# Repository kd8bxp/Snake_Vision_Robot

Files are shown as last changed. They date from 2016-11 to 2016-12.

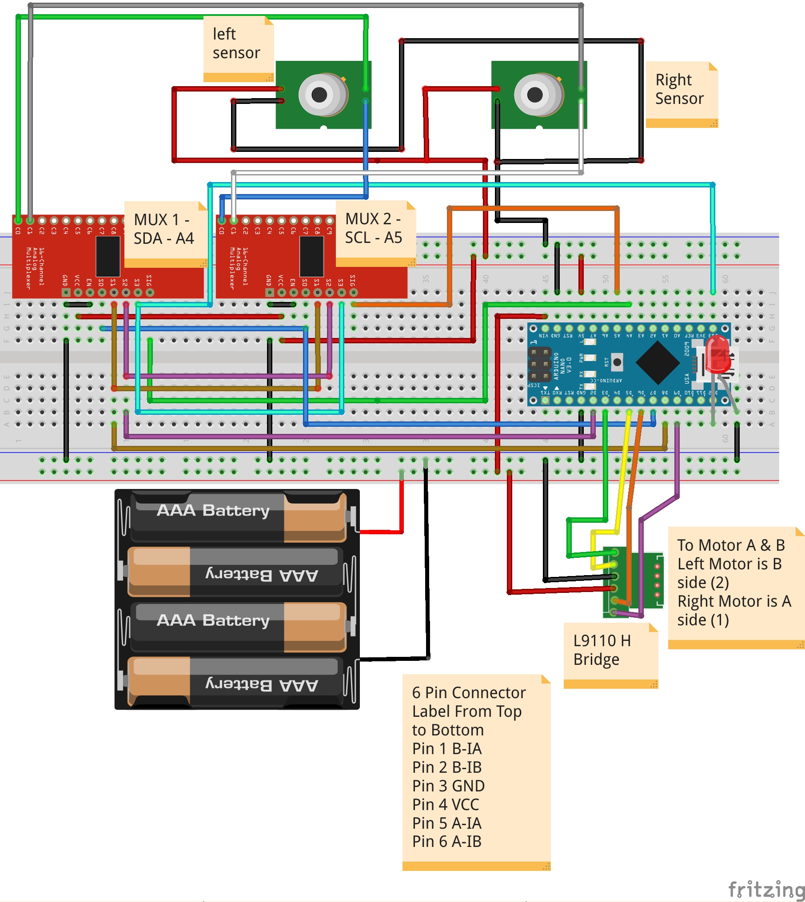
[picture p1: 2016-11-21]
documents/Snake Vision Robot_bb.jpg

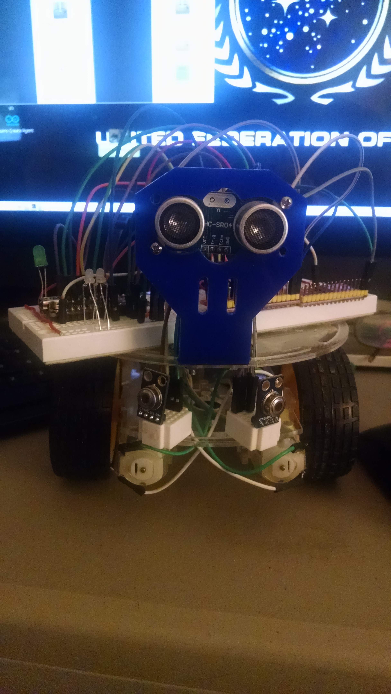
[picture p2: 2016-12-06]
documents/2016-12-05 19.06.58.jpg

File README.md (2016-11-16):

# Snake Vision Robot

The idea is that the robot is attracted to heat, and will move toward it.
The setup is to have the MLX90614 sensors set at an angle from each other, 
IF one sees more heat than the other, the robot will turn in that direction, and will attempt to move to the source.

The MLX90614 sensors were provided by IC Station for this experiment.
http://www.icstation.com/mlx90614esf-human-body-infrared-temperature-sensor-contact-temperature-module-p-9911.html

The sensors are I2C, and a MUX will be used to switch between the two sensors

## Parts

Heat Seeking robot based on 2 IC Station MLX90614ESF Human Body Infrared Temperature Sensors
Using a L9110 Motor Driver, and 2 CD74HC4067 MUX boards. 
With an Arduino Nano for it's brains.

## Contributing

1. Fork it!
2. Create your feature branch: `git checkout -b my-new-feature`
3. Commit your changes: `git commit -am 'Add some feature'`
4. Push to the branch: `git push origin my-new-feature`
5. Submit a pull request

## Credits

LeRoy Miller (2016).

## License

This program is free software: you can redistribute it and/or modify
    it under the terms of the GNU General Public License as published by
    the Free Software Foundation, either version 3 of the License, or
    (at your option) any later version.

    This program is distributed in the hope that it will be useful,
    but WITHOUT ANY WARRANTY; without even the implied warranty of
    MERCHANTABILITY or FITNESS FOR A PARTICULAR PURPOSE.  See the
    GNU General Public License for more details.

    You should have received a copy of the GNU General Public License
    along with this program.  If not, see <http://www.gnu.org/licenses>

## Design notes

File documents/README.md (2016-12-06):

# Snake Vision Robot

http://www.instructables.com/id/Snake-Vision-Robot-Using-Two-MLX90614-No-Contact-T/

## Not on Fritzing drawing

Updated parts list: on Dec 6, 2016 added a HC-SR04 ultrasonic sensor.
Echo Pin to Pin 10 on Nano
Trigger Pin to Pin 11 on Nano
VCC to 5v bus, GND to GND

## Contributing

1. Fork it!
2. Create your feature branch: `git checkout -b my-new-feature`
3. Commit your changes: `git commit -am 'Add some feature'`
4. Push to the branch: `git push origin my-new-feature`
5. Submit a pull request

## Credits

LeRoy Miller (2016).

## License

This program is free software: you can redistribute it and/or modify
    it under the terms of the GNU General Public License as published by
    the Free Software Foundation, either version 3 of the License, or
    (at your option) any later version.

    This program is distributed in the hope that it will be useful,
    but WITHOUT ANY WARRANTY; without even the implied warranty of
    MERCHANTABILITY or FITNESS FOR A PARTICULAR PURPOSE.  See the
    GNU General Public License for more details.

    You should have received a copy of the GNU General Public License
    along with this program.  If not, see <http://www.gnu.org/licenses>

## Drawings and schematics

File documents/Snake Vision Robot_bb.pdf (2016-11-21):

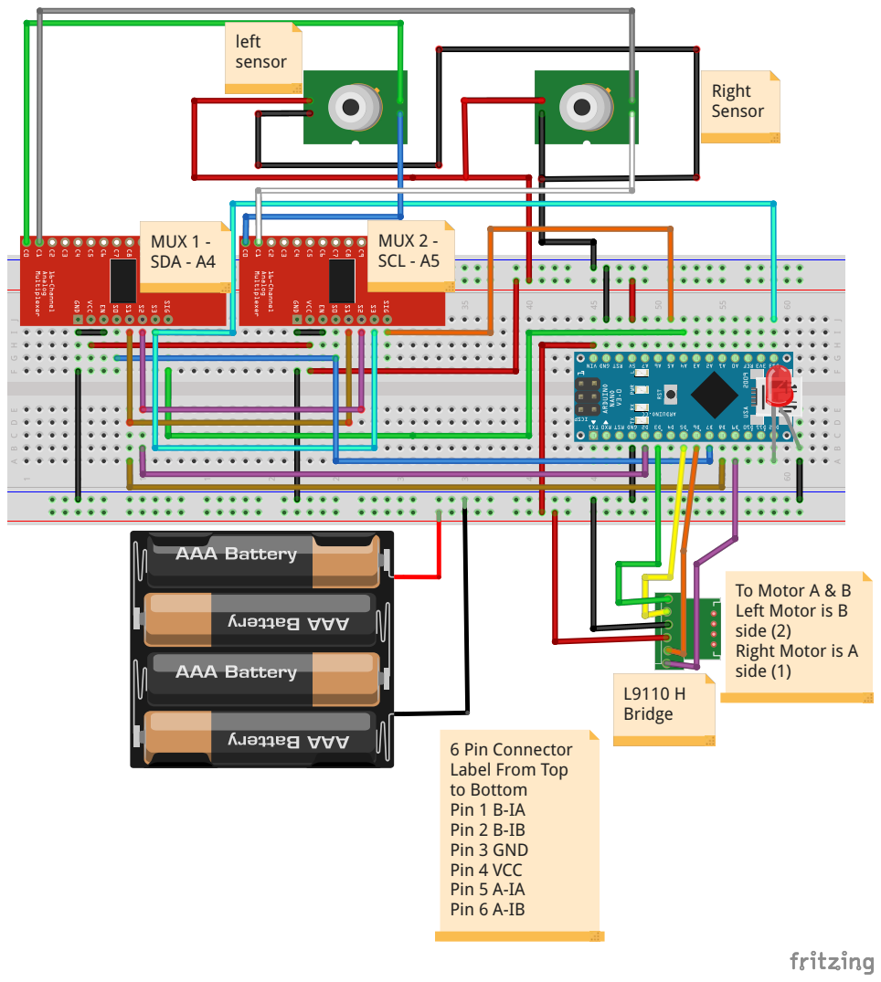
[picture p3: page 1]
L9110 H Bridge; MUX 1 - SDA - A4; MUX 2 - SCL - A5; left sensor; Right Sensor

To Motor A & B
Left Motor is B
side (2)
Right Motor is A
side (1)

6 Pin Connector
Label From Top
to Bottom
Pin 1 B-IA
Pin 2 B-IB
Pin 3 GND
Pin 4 VCC
Pin 5 A-IA
Pin 6 A-IB

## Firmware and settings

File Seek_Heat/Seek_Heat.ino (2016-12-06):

/* 2-Way motor control for the L9110 motor driver adapted from
 * https://www.bananarobotics.com/shop/How-to-use-the-HG7881-(L9110)-Dual-Channel-Motor-Driver-Module
 * 
 * Multiplexer code based on information found
 * http://bildr.org/2011/02/cd74hc4067-arduino/
 * and https://www.sparkfun.com/products/9056
 * 
 * Adapted by LeRoy Miller, 2016 (Copyright)
 * 
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
    You should have received a copy of the GNU General Public License
    along with this program.  If not, see <http://www.gnu.org/licenses>
 */

// Seek Heat.

#include <Wire.h>
#include <Adafruit_MLX90614.h>
#include <NewPing.h>

Adafruit_MLX90614 mlx = Adafruit_MLX90614(); 
#define units 1 //1=Fahrenheit,  0=Celius

//Functions:

//rightForward(speed)
//rightBackward(speed)
//leftForward(speed)
//leftBackward(speed)
//stop()
//readRightSensor() - set the mux to read the sensor connected to C0
//readLeftSensor() - set the mux to read the sensor connected to C1
//readSensor() - returns value of current readings

//Setup  variables for UltraSonic
int pingSensorIn;
int goRobotGo = 0; //Should the robot be moving or stopped
#define distance 5 //Stop distance in Inches
#define TRIGGER_PIN  11  // Arduino pin tied to trigger pin on the ultrasonic sensor.
#define ECHO_PIN     10  // Arduino pin tied to echo pin on the ultrasonic sensor.
#define MAX_DISTANCE 200 // Maximum distance we want to ping for (in centimeters). Maximum sensor distance is rated at 400-500cm.

NewPing sonar(TRIGGER_PIN, ECHO_PIN, MAX_DISTANCE); // NewPing setup of pins and maximum distance.


//Setup variables for motors
#define leftMotorPin1   3 //Left IA2   PWM PIN
#define leftMotorPin2   5 //Left IB2 Direction PIN 
#define rightMotorPin1  6 //Right IA1 PWM PIN
#define rightMotorPin2  9 //Right IB1 Direction PIN
#define pwmR  140 //smallest PWM value that will cause motor to spin
#define pwmL  125

//Setup variables for temperature sensors

int rightSensor;
int leftSensor;
int rightAmbient; //ambient temperature of sensors
int leftAmbient;
int rightCalibrate;
int leftCalibrate;
int aL;
int sL;
int aR;
int sR;


//Variables for Mux. (multiplexer)
/* Special cases - 2 Mux boards are used, one is used for SDA, and
 *  the other is used for SCL. There are two thermal sensors, so only
 *  2 of the 16 ports on the mux are needed, meaning, only one
 *  of the mux control lines needs to be changed to read the two sensors
 *  The code would need to be changed, and expanded to add more I2C sensors
 */

#define s0  7
#define s1  8
#define s2  2
#define s3 13

//RED temperatures are higher than ambient, GREEN ambient temperature
#define LED 12  //ready indicator (GREEN)
#define RIGHTREDLED A0 
#define RIGHTGREENLED A1
#define LEFTREDLED A2
#define LEFTGREENLED A3


void setup()   {  
   Serial.begin(9600);
   mlx.begin();
   pinMode(LED, OUTPUT);
   pinMode(s0, OUTPUT);
   pinMode(s1, OUTPUT);
   pinMode(s2, OUTPUT);
   pinMode(s3, OUTPUT);
   pinMode(RIGHTREDLED, OUTPUT);
   pinMode(RIGHTGREENLED, OUTPUT);
   pinMode(LEFTREDLED, OUTPUT);
   pinMode(LEFTGREENLED, OUTPUT);
   pinMode(leftMotorPin1, OUTPUT); 
   pinMode(leftMotorPin2, OUTPUT);  
   pinMode(rightMotorPin1, OUTPUT);
   pinMode(rightMotorPin2, OUTPUT);
   digitalWrite(s0, LOW);
   digitalWrite(s1, LOW);
   digitalWrite(s2, LOW);
   digitalWrite(s3, LOW);
   digitalWrite(RIGHTREDLED, LOW);
   digitalWrite(RIGHTGREENLED, LOW);
   digitalWrite(LEFTREDLED, LOW);
   digitalWrite(LEFTGREENLED, LOW);
  stop();
  delay(5000); //delay before calibration - warning sensors are very senitive point them away from any type of heat source.
  calibrateSensors(); 
 delay(5000);  //another delay after calibration (a buzzer might go good here, warning that the bot is just about ready)
 digitalWrite(LED, HIGH); //When LED comes on ROBOT is Ready to move.
 
}

void loop()                     
{

readRightSensor();
readLeftSensor();
readPing();
if (goRobotGo) {
aL = map(leftAmbient, -40, leftAmbient, 0.0, pwmR);
sL = map(leftSensor, leftAmbient, leftSensor, pwmR, 0.0);
aR = map(rightAmbient, -40, rightAmbient, 0.0, pwmL);
sR = map(rightSensor, rightAmbient, rightSensor, pwmL, 0.0);
if (leftAmbient >= leftSensor) {sL = pwmR;}
if (rightAmbient >= rightSensor) {sR = pwmL;}
rightForward(aL - sL);
leftForward(aR - sR);
} else { stop(); }
//delay(50); //test code with small delay (may not be needed)

}

void readPing() {
 
   unsigned int uS = sonar.ping(); // Send ping, get ping time in microseconds (uS).
   pingSensorIn = (uS / US_ROUNDTRIP_IN);
   if (pingSensorIn >= distance) {goRobotGo = 1; } else {goRobotGo = 0;}

}

void readRightSensor() {
  digitalWrite(s0, LOW);
  //because S1, S2, S3 are already set LOW we don't need to set again
  rightSensor = readSensor() + rightCalibrate;
  rightAmbient = readAmbient();
  if (rightAmbient >= rightSensor) { 
    digitalWrite(RIGHTGREENLED, HIGH); 
    digitalWrite(RIGHTREDLED, LOW); } else {
        digitalWrite(RIGHTGREENLED, LOW);
        digitalWrite(RIGHTREDLED, HIGH);
    }
  }

void readLeftSensor() {
  digitalWrite(s0, HIGH);
  //because s1, s2, s3 are already set LOW we don't need to set again
  leftSensor = readSensor() + leftCalibrate;
  leftAmbient = readAmbient();
  if (leftAmbient >= leftSensor) { 
    digitalWrite(LEFTGREENLED, HIGH); 
    digitalWrite(LEFTREDLED, LOW); } else {
        digitalWrite(LEFTGREENLED, LOW);
        digitalWrite(LEFTREDLED, HIGH);
    }
}

int readSensor() {
  
  /* Code to read the Thermal sensor goes here 
   *  and should return a value back to the calling function
   */
   
   int temp;
   if (units) {temp = mlx.readObjectTempF();} else {temp = mlx.readObjectTempC();} 
   return temp;
   
}

int readAmbient() {
  
  // Code to read the Thermal sensor Ambient Tempature
  
  int temp;
  if (units) {temp = mlx.readAmbientTempF();} else {temp = mlx.readAmbientTempC();}
  return temp;
  
}

void rightForward(int speedOfRotate) {
  digitalWrite(rightMotorPin2, LOW);
  analogWrite(rightMotorPin1, speedOfRotate);
}

void rightBackward(int speedOfRotate) {
  digitalWrite(rightMotorPin2, HIGH);
  analogWrite(rightMotorPin1, speedOfRotate);
}

void leftForward(int speedOfRotate) {
  digitalWrite(leftMotorPin2, LOW);
  analogWrite(leftMotorPin1, speedOfRotate);
}

void leftBackward(int speedOfRotate) {
  digitalWrite(leftMotorPin2, HIGH);
  analogWrite(leftMotorPin1, speedOfRotate);
}

void stop() {
  digitalWrite(leftMotorPin1, LOW);
  digitalWrite(leftMotorPin2, LOW);
  digitalWrite(rightMotorPin1, LOW);
  digitalWrite(rightMotorPin2, LOW);
}

void calibrateSensors() {
  int avg1 = 0;
  int avg2 = 0;
  
  Serial.print("Calibrate Sensors.");
  
  for (int i=0; i<=100; i++) {
    Serial.print(".");
    readRightSensor();
  avg1 = avg1 + rightSensor;
  avg2 = avg2 + rightAmbient;  
  }
  avg1 = avg1 / 100;
  avg2 = avg2 / 100;
  
  rightCalibrate = avg2 - avg1;
  
  avg1 = 0;
  avg2 = 0;
  for (int i=0; i<=100; i++) {
    Serial.print(".");
    readLeftSensor();
    avg1 = avg1 + leftSensor;
    avg2 = avg2 + leftAmbient;
  }
  avg1 = avg1 / 100;
  avg2 = avg2 / 100;
  leftCalibrate = avg2 - avg1;
  Serial.println("");
  Serial.print("Right Calibrate: ");
  Serial.print(rightCalibrate);
  Serial.print(" Left Calibrate: ");
  Serial.println(leftCalibrate);
}

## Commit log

2016-11-20 added calibration code for sensors, minor changes from testing branch
2016-11-20 changed motor logic, added led for start
2016-11-21 added fritzing pictures
    [Snake Vision Robot.fzz]
2016-11-26 fix logic error found while making instructable
    [Snake_Vision_Robot.ino]
